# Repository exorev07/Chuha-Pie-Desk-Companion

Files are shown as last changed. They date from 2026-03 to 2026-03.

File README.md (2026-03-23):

<div align="center">
   
# Chuha Pie V1 - A cute Desk Companion
*An ESP32-powered animated desk companion with OLED eyes, touch interactions, Spotify controls, presence detection, and environmental monitoring, housed in a custom 3D-printed enclosure.*







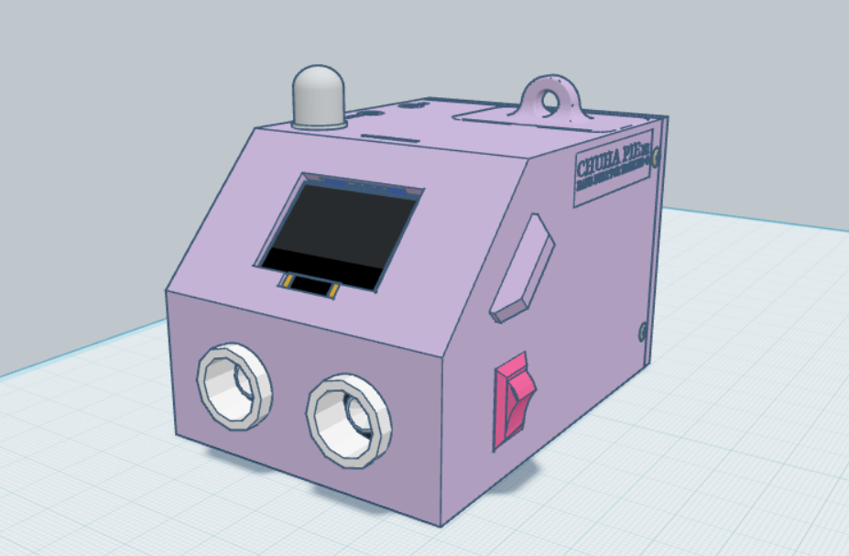
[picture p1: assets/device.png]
Device


</div>

---

## 📖 Table of Contents

- [Overview](#-overview)
- [Repository Structure](#-repository-structure)
- [Hardware](#-hardware)
- [Features](#-features)
- [Pin Connections](#-pin-connections)
- [Libraries Required](#-libraries-required)
- [Getting Started](#-getting-started)
- [Power](#-power)
- [License](#-license)

---

## 🔍 Overview

Chuha Pie V1 is a hand-built desk companion that I built for my girlfriend as her 20th birthday present, which sits on her desk and keeps her company. It uses an OLED display with animated eyes to express its mood, reacts to presence and touch, gives her break and water reminders, tracks and controls Spotify playback on any device using the account, runs a stopwatch and a Pomodoro timer, and measures distance digitally, along with ambient temperature and humidity in the room - all running on an ESP32.

**Key highlights:**

- **Animated OLED eyes** with blink, idle movement, and mood expressions.
- **Touch interactions** - tap, double tap, triple tap, and long press gestures.
- **Presence detection** via HC-SR04  greets and gets excited when it detects presence, gets sad otherwise.
- **Spotify control** - play/pause, next, previous track - through touch controls.
- **Pomodoro timer** with auto-start (10s), pause/resume, and configurable durations from the internal menu.
- **Passive wellness reminders** - posture alerts, break reminders, water reminders via RGB LED.
- **Environmental display** - temperature, humidity, distance readouts on demand
- **Deep sleep via physical switch** - turns off even with USB connected

---

## 📁 Repository Structure

```text
Chuha Pie V1/
├── 📂 3D Print Enclosure/
│   ├── back_plate.stl
│   ├── esp_button_connector.stl
│   └── main_body.stl
|
├── 📂 Main/
│   ├── Main.ino                      # Main firmware
│   └── example_secrets.h             # This is an example file - Upon downloading, rename to secrets.h and follow the instructions.
│
├── 📂 assets/
│   └── device.png                    # 3D render of the device
│
├── .gitignore
├── CMD Serial Monitor.txt            # Use to read serial data from ESP32 in Spotify Mode
├── spotify_get_refresh_token.py      # Helper script to generate Spotify refresh token
├── Chuha Pie User Manual.pdf         # Detailed instructions
├── LICENSE
└── README.md
```

---

## 🪛 Hardware

| Component | Model |
|---|---|
| Microcontroller | ESP32 DevKit V1 |
| Display | SSD1306 128×64 OLED (SPI, 7-pin) |
| Touch Sensor | TTP223 Capacitive Touch |
| Ultrasonic Range Sensor | HC-SR04 |
| Temp/Humidity | DHT11 |
| Indicator | RGB LED (Common Anode, 10mm diffused) |
| Haptics | 5V Vibration Motor Module (3-pin) |
| Sleep Control | SPST Switch (deep sleep via GPIO 35) |
| Power | USB via ESP32 DevKit V1 |

---

## ✨ Features

> See the [User Manual](./Chuha%20Pie%20User%20Manual.pdf) included in the repo for a full visual flowchart of touch interactions.

### Touch Interactions (TTP223)

| Gesture | Action |
|---|---|
| Single tap | Enter Feature Cycle (starts at Date & Time) |
| Double tap | Bonk animation |
| Triple tap | Open Settings |
| Long press (1s) | Cycle to next feature mode |
| Long press (2s+) | Pet the bot — happy animation |
| Long press (4s) | Return to Home Screen from any mode |

### Feature Cycle

**Home → Date & Time → Stopwatch → Pomodoro → Spotify → Distance → Temperature → Humidity → Home**

> **Shortcut**: Long press advances to the next mode. A 4-second long press from any mode jumps directly to home.

| Mode | Single Tap | Double Tap | Triple Tap |
|---|---|---|---|
| Date & Time | Toggle 12h / 24h format | — | — |
| Stopwatch | Start / Pause | Reset | — |
| Pomodoro (select) | Cycle duration options | — | — |
| Pomodoro (running) | Pause / Resume | — | — |
| Spotify | Play / Pause | Next song | Previous song |

### Settings (Triple Tap from Home)

- **Brightness**: 5 levels: 5% / 25% / 50% / 75% / 100%
- **Presence Range** (long press from Brightness): configures detection distance to 30 / 50 / 75 / 100 / 125 cm. The posture alert threshold adjusts proportionally (~40% of the detection distance).

### Automatic / Background Features

| Feature | Trigger | Indicator |
|---|---|---|
| Presence detection | Enters detection range | Greeting eye animation |
| Sad eyes | No presence for 30+ seconds | Eye animation |
| Break reminder | 1 hour of continuous presence | Green LED + vibration |
| Posture alert | Too close for 3+ seconds | Red LED + vibration (1 min cooldown) |
| Water reminder | Every hour / 1 min after 30+ min absence | Blue LED + vibration |
| Sweat animation | Temperature > 35°C | Eye animation (10s every 5 min) |
| Auto brightness | Time of day | 100% (7AM–7PM), 50% (7PM-7AM), 75% (No Internet default) |

---

## 📌 Pin Connections

### OLED Display (SPI)

| OLED Pin | ESP32 Pin |
|---|---|
| GND | GND |
| VDD | 3.3V |
| SCK | GPIO 18 (HSPI CLK) |
| SDA | GPIO 23 (HSPI MOSI) |
| RES | GPIO 4 |
| DC | GPIO 2 |
| CS | GPIO 5 |

### TTP223 Touch Sensor

| Pin | ESP32 Pin |
|---|---|
| VCC | 3.3V |
| GND | GND |
| SIG | GPIO 15 |

### HC-SR04 Ultrasonic Sensor

| Pin | ESP32 Pin |
|---|---|
| VCC | VIN (5V) |
| GND | GND |
| TRIG | GPIO 26 |
| ECHO | Voltage divider → GPIO 27 |

> ⚠️ **HC-SR04 ECHO outputs 5V but ESP32 GPIO is 3.3V tolerant only.**
> Wire a voltage divider on ECHO: `ECHO → 1kΩ → GPIO 27 → 2kΩ → GND` (divides 5V to ~3.3V)

### DHT11

| Pin | ESP32 Pin |
|---|---|
| VCC | 3.3V |
| GND | GND |
| DATA | GPIO 14 |

### RGB LED (Common Anode)

| Pin | ESP32 Pin | Notes |
|---|---|---|
| Anode (longest) | 3.3V | — |
| Red | GPIO 25 | 100Ω resistor in series |
| Green | GPIO 32 | No resistor (Vf ~3.0–3.4V) |
| Blue | GPIO 33 | No resistor (Vf ~3.0–3.4V) |

### Vibration Motor (3-pin module)

| Pin | ESP32 Pin |
|---|---|
| VCC | VIN (5V) |
| GND | GND |
| SIG | GPIO 13 |

### Power Switch

```
GND → 10kΩ → GPIO 35 → [switch] → 3.3V
```

- Switch **open (OFF)**: GPIO 35 reads LOW → ESP32 enters deep sleep
- Switch **closed (ON)**: GPIO 35 reads HIGH → device runs normally

> GPIO 35 is input-only with no internal pull resistor - the external 10kΩ to GND is required.

---

## 📚 Libraries Required

Install via Arduino IDE → **Tools → Manage Libraries**:

| Library | Author |
|---|---|
| `Adafruit SSD1306` | Adafruit |
| `Adafruit GFX Library` | Adafruit |
| `DHT sensor library` | Adafruit |
| `FluxGarage RoboEyes` | FluxGarage |

---

## 🚀 Getting Started

### Prerequisites

- [Arduino IDE](https://www.arduino.cc/en/software) (v1.8+ or v2.x)
- ESP32 board package installed in Arduino IDE
- Python 3.x (for Spotify token helper script)
- A 2.4GHz WiFi network
- Spotify Premium account _(for Spotify feature)_

### 1️⃣ Get the Code

```bash
git clone https://github.com/exorev07/Chuha-Pie-Desk-Companion.git
```

Or download the ZIP from GitHub and extract it.

### 2️⃣ Set Up Arduino IDE

1. Open Arduino IDE → **File → Preferences**
2. Under _Additional Boards Manager URLs_, paste:

   ```text
   https://raw.githubusercontent.com/espressif/arduino-esp32/gh-pages/package_esp32_index.json
   ```

3. Go to **Tools → Board → Boards Manager**, search `esp32`, and install it
4. Go to **Tools → Manage Libraries** and install all four libraries listed above

### 3️⃣ Configure Your Credentials

1. Copy `Main/example_secrets.h` and rename the copy to `Main/secrets.h`
2. Open `Main/secrets.h` and fill in your details:

   ```cpp
   #define WIFI_SSID_VAL     "WiFi Name (2.4GHz)"
   #define WIFI_PASSWORD_VAL "WiFi Password"

   #define SPOTIFY_CLIENT_ID_VAL     "paste Client ID here"
   #define SPOTIFY_CLIENT_SECRET_VAL "paste Client Secret here"
   #define SPOTIFY_REFRESH_TOKEN_VAL "paste Refresh Token here"
   ```

### 4️⃣ Setting Up Spotify

1. Go to [developer.spotify.com/dashboard](https://developer.spotify.com/dashboard) and create an app
2. Set the redirect URI to `http://127.0.0.1:8888/callback`
3. Copy your **Client ID** and **Client Secret** into `secrets.h`
4. Run the included helper script to get your Refresh Token:

   ```bash
   python spotify_get_refresh_token.py
   ```

5. Paste the printed Refresh Token into `secrets.h`

> Chuha Pie V1 can control whichever device is currently active on the Spotify account.

### 5️⃣ Upload to the Device

1. Plug in the device via USB
2. In Arduino IDE: **Tools → Board** → select **ESP32 Dev Module** or **DOIT ESP32 DevKit V1**
3. **Tools → Port** → select the COM port that appears (e.g. COM3 on Windows)
4. Click the **Upload** button (→)
5. If the IDE shows `Connecting...`, hold the **BOOT** button on the ESP32 until uploading starts
6. Wait for _"Done uploading"_ - Chuha Pie restarts automatically

---

## ⚡ Power

- Powered via USB through the ESP32 DevKit V1 
- The physical switch triggers ESP32 **deep sleep**
- To wake: flip the switch to ON (GPIO 35 goes HIGH, ESP32 exits deep sleep and reboots)

---

## 📜 License

This project is licensed under the **MIT License** - see the [LICENSE](LICENSE) file for details.

---

<div align="center">

**If you like this project, consider giving it a ⭐!**

_Built with 💜 for the love of my life._

</div>

---

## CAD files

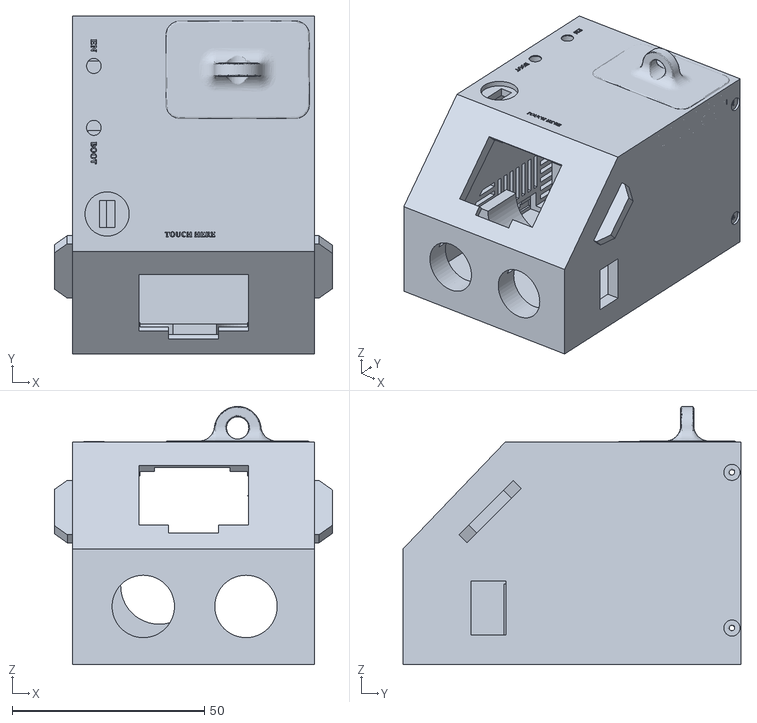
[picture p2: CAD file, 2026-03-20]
3D Print Enclosure/main_body.stl
72.5 x 88.0 x 67.2

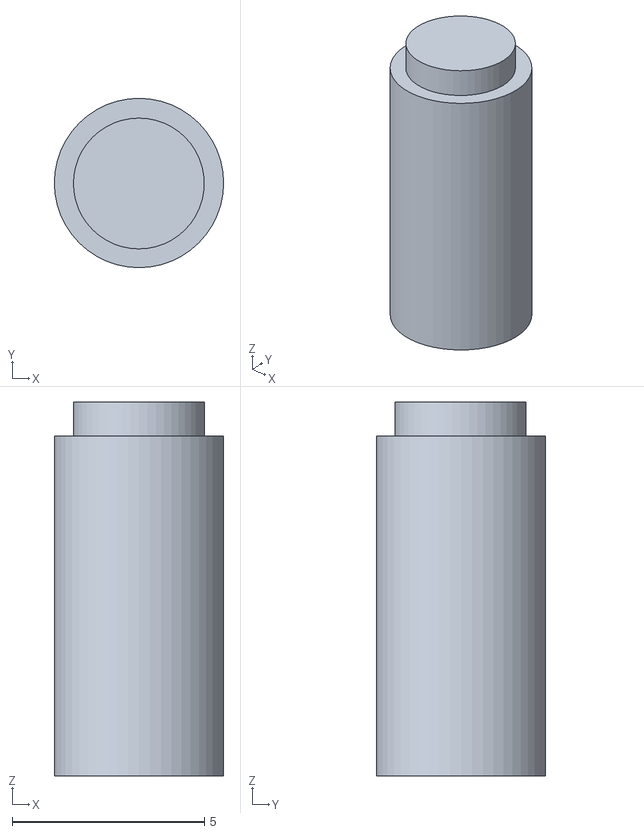
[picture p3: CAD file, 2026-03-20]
3D Print Enclosure/esp_button_connector.stl
4.40 x 4.40 x 9.72

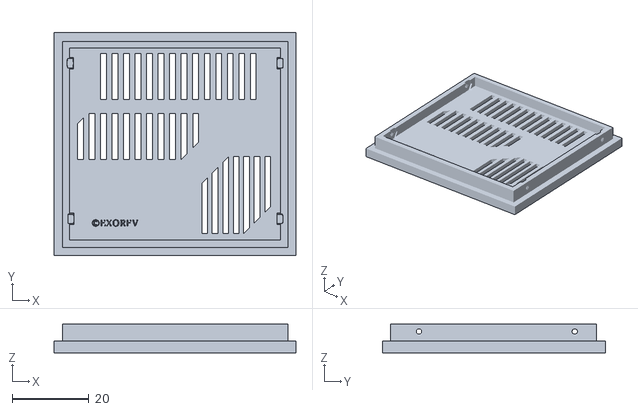
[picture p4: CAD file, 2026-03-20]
3D Print Enclosure/back_plate.stl
63.0 x 58.0 x 7.51

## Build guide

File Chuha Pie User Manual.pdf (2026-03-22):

# CHUHA PIE

V1

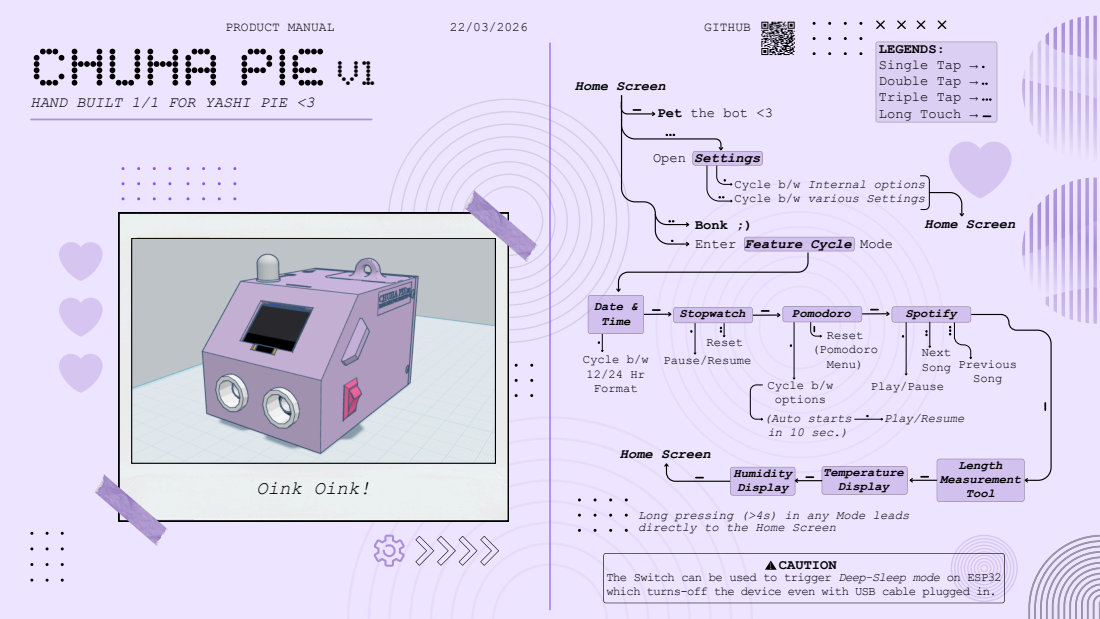
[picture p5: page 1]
Open Settings; Stopwatch; Pomodoro; Cycle b/w options (Auto starts in 10 sec.); Reset (Pomodoro Menu); Spotify; Next Song Previous Song; Length Measurement Tool; LEGENDS: Single Tap → Double Tap → Triple Tap → Long Touch →; CAUTION; Temperature Display; Home Screen; Humidity Display; Oink Oink!; PRODUCT MANUAL; Date & Time; Cycle b/w 12/24 Hr Format; Pause/Resume; Reset; Play/Pause; GITHUB; Play/Resume

HAND BUILT 1/1 FOR YASHI PIE <3

Pet the bot <3

Cycle b/w Internal options
Cycle b/w various Settings
Bonk ;)
Enter Feature Cycle Mode

Long pressing (>4s) in any Mode leads
directly to the Home Screen

The Switch can be used to trigger Deep-Sleep mode on ESP32
which turns-off the device even with USB cable plugged in.

# CHUHA PIE

### HAND BUILT 1/1 FOR YASHI PIE <3

V1

SETUP | 22/03/2026

GITHUB (https://github.com/exorev07/Chuha-Pie-Desk-Companion.git)

GETTING STARTED
What you'll need:
1.A computer with USB port.
2.Arduino IDE.
3.USB cable (Micro-USB) - Supplied with the device. 4.WiFi connection to use Spotify Controls and sync time. 5.Spotify Premium account (for Spotify feature).

STEP-1: GET THE CODE
1.Go to the GitHub link -
github.com/exorev07/Chuha-Pie-Desk-Companion.git 2.Download ZIP.
3.Extract the ZIP to access the code.
OR if you have Git installed: git clone.

STEP-2: SET UP ARDUINO IDE
1.Open Arduino IDE
2.Go to File → Preferences
3.Under Additional Boards Manager URLs, | paste:
4.Go to Tools → Board → Boards Manager, | search esp32, install it
5.Go to Tools → Manage Libraries, search and install:
Adafruit SSD1306
Adafruit GFX Library
DHT sensor library by Adafruit FluxGarage RoboEyes

https://raw.githubusercontent.com/espressif/arduino-%20esp32/gh-pages/package_esp32_index.json (https://raw.githubusercontent.com/espressif/arduino-%20esp32/gh-pages/package_esp32_index.json)

STEP-3: CONFIGURE YOUR CREDENTIALS
1.Open the extracted folder & open Main/secrets.h in Arduino IDE 2.Find these lines & fill them in:
#define WIFI_SSID_VAL "Enter 2.4Ghz SSID here" #define WIFI_PASSWORD_VAL "ENTER WIFI Password"

STEP-4: | SET UP SPOTIFY
1.Go to | developer.spotify.com/dashboard and log in
2.Click | Create App - name it anything, set redirect URI to
http://localhost:8888/callback
3.Copy your Client ID and Client Secret, Value into secrets.h: #define SPOTIFY_CLIENT_ID_VAL "Paste here"
#define SPOTIFY_CLIENT_SECRET_VAL "Paste here" 4.To get your Refresh Token:

Run spotify_get_refresh_token.py from the Product Repo. 5.Log in with your Spotify account and grant permissions 6.Copy the Refresh Token and paste it into secrets.h: #define SPOTIFY_REFRESH_TOKEN_VAL "Paste here"

STEP-5: UPLOAD TO THE DEVICE
1.Plug in Chuha Pie via USB
2.In Arduino IDE go to Tools → Board → select ESP32 Dev Module or DOIT ESP32 Devkit V1
3.Go to Tools → Port → select the COM port that appears (e.g. COM3 on Windows)
4.Click the Upload button.
5.Wait for IDE to upload and when it displays “connecting...” press and hold boot button on ESP32 and the Device will restart automatically.

Auto Brightness
The device adjusts screen brightness automatically
based on time of day
7:00 AM - 7:00 PM → Full brightness (100%)
7:00 PM – 7:00 AM → Dimmed (50%)
If the device can't connect to NTP server, it defaults to 75% brightness.

exorev07

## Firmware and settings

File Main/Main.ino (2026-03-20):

/*
 * Chuha Pie V1 - Desk Companion
 * 
 * Hardware:
 * - ESP32 DevKit V1
 * - 7-Pin SSD1306 OLED (128x64, SPI)
 * - TTP223 Capacitive Touch Sensor
 * - HC-SR04 Ultrasonic Distance Sensor
 * - DHT11 Temperature & Humidity Sensor
 * - Vibration Motor (5V, GPIO-driven)
 * - RGB LED (Common Anode, 10mm diffused)
 * 
 * Pin Connections:
 * OLED GND  -> ESP32 GND
 * OLED VDD  -> ESP32 3.3V
 * OLED SCK  -> ESP32 GPIO 18 (HSPI CLK)
 * OLED SDA  -> ESP32 GPIO 23 (HSPI MOSI)
 * OLED RES  -> ESP32 GPIO 4 (Reset)
 * OLED DC   -> ESP32 GPIO 2 (Data/Command)
 * OLED CS   -> ESP32 GPIO 5 (Chip Select)
 * 
 * TTP223 VCC -> ESP32 3.3V
 * TTP223 GND -> ESP32 GND
 * TTP223 SIG -> ESP32 GPIO 15
 * 
 * HC-SR04 VCC  -> ESP32 VIN or 5V pin
 * HC-SR04 GND  -> ESP32 GND
 * HC-SR04 TRIG -> ESP32 GPIO 26
 * HC-SR04 ECHO -> VOLTAGE DIVIDER -> ESP32 GPIO 27
 * 
 * ⚠️ IMPORTANT: HC-SR04 ECHO outputs 5V but ESP32 GPIO is 3.3V tolerant!
 * Use voltage divider on ECHO pin:
 *   ECHO -> 1kΩ resistor -> GPIO 27 -> 2kΩ resistor -> GND
 *   This divides 5V to ~3.3V (safe for ESP32)
 * 
 * DHT11 VCC  -> ESP32 3.3V
 * DHT11 GND  -> ESP32 GND
 * DHT11 DATA -> ESP32 GPIO 14
 * 
 * Vibration Motor VCC -> ESP32 VIN (5V)
 * Vibration Motor GND -> ESP32 GND
 * Vibration Motor SIG -> ESP32 GPIO 13
 * 
 * Power Switch:
 * GND -> 10kΩ -> GPIO 35 -> [switch] -> 3.3V
 * Switch open (OFF): GPIO35 LOW -> device enters deep sleep
 * Switch closed (ON): GPIO35 HIGH -> device runs
 *
 * RGB LED (Common Anode, 10mm diffused):
 * RGB LED Anode (longest pin) -> ESP32 3.3V
 * RGB LED Red   -> 100Ω resistor -> ESP32 GPIO 25
 * RGB LED Green -> ESP32 GPIO 32 (no resistor needed, Vf ~3.0-3.4V)
 * RGB LED Blue  -> ESP32 GPIO 33 (no resistor needed, Vf ~3.0-3.4V)
 * 
 * Features:
 * - Touch interactions: single tap (mode enter), double tap (bonk), triple tap (brightness)
 * - Long press (>2s): Happy mood with laugh animation + haptic feedback
 * - 1s long press: Cycles through modes (Time > Stopwatch > Pomodoro > Spotify > Distance > Temp > Humidity)
 * - 4s long press: Home shortcut (return to eyes from any display mode)
 * - Time display with 12hr/24hr toggle (tap to switch)
 * - Stopwatch with start/pause (tap) and reset (double tap)
 * - Pomodoro timer (30/45/60/90/120 min, pause/resume, 10s auto-start)
 * - Spotify control: play/pause (tap), next (double tap), prev (triple tap)
 * - Distance, temperature, humidity displays
 * - Brightness adjustment: 5 levels via 3 SSD1306 registers (triple tap from eyes)
 * - Time-based default brightness: 100% daytime (7AM-7PM), 50% nighttime
 * - Presence detection: greets on arrival, shows TIRED after 30s absence
 * - Break reminder: hourly while present (green LED)
 * - Posture alert: too close (<20cm for 3s) with 1min cooldown (red LED)
 * - Water reminder: hourly + 1min after return from 30min absence (blue LED)
 * - RGB LED pulses with vibration for 2s, then solid for 3s during alerts
 * - Sweat animation above 35°C (10s every 5min)
 * - Auto blink and idle eye movements
 */

#include <SPI.h>
#include <Adafruit_GFX.h>
#include <Adafruit_SSD1306.h>
#include <WiFi.h>
#include <WiFiClientSecure.h>
#include <HTTPClient.h>
#include "base64.h"
#include <time.h>
#include <DHT.h>
#include <FluxGarage_RoboEyes.h>
#include "secrets.h"

// ============ WIFI CREDENTIALS ============
const char* WIFI_SSID = WIFI_SSID_VAL;
const char* WIFI_PASSWORD = WIFI_PASSWORD_VAL;

// ============ SPOTIFY CREDENTIALS ============
// Edit credentials in secrets.h (that file is gitignored and never pushed)
const char* SPOTIFY_CLIENT_ID = SPOTIFY_CLIENT_ID_VAL;
const char* SPOTIFY_CLIENT_SECRET = SPOTIFY_CLIENT_SECRET_VAL;
const char* SPOTIFY_REFRESH_TOKEN = SPOTIFY_REFRESH_TOKEN_VAL;

// ============ TIME CONFIGURATION ============
const char* NTP_SERVER = "pool.ntp.org";
const long GMT_OFFSET_SEC = 19800;  // IST is GMT+5:30 (5.5 * 3600 = 19800 seconds)
const int DAYLIGHT_OFFSET_SEC = 0;   // India doesn't use daylight saving

// ============ PIN DEFINITIONS ============
#define OLED_MOSI   23
#define OLED_CLK    18
#define OLED_DC     2
#define OLED_CS     5
#define OLED_RESET  4
#define TOUCH_PIN   15
#define TRIG_PIN    26
#define ECHO_PIN    27 
#define DHT_PIN     14 
#define VIBRATION_PIN 13
#define LED_RED_PIN   25
#define LED_GREEN_PIN 32
#define LED_BLUE_PIN  33
#define POWER_SWITCH_PIN 35  // Input-only RTC GPIO, external 10kΩ pulldown to GND, switch to 3.3V

// RGB LED PWM channels (common anode: 0=full on, 255=off)
#define LED_RED_CH    0
#define LED_GREEN_CH  1
#define LED_BLUE_CH   2

// ============ DHT11 SENSOR CONFIG ============
#define DHT_TYPE DHT11
DHT dht(DHT_PIN, DHT_TYPE);

// ============ TEMPERATURE MONITORING ============
#define TEMP_CHECK_INTERVAL 10000   // Check temperature every 10 seconds
#define SWEAT_THRESHOLD 35.0        // Sweating animation above 35°C
#define SWEAT_INTERVAL 300000UL     // Sweat every 5 minutes
#define SWEAT_DURATION 10000        // Sweat for 10 seconds
unsigned long lastTempCheck = 0;
unsigned long lastSweatStart = 0;    // When last sweat episode started
float lastTemperature = 0;
bool isSweating = false;

// ============ DISTANCE SENSOR CONFIG ============
#define DISTANCE_CHECK_INTERVAL 500  // Check distance every 500ms
float smoothedDistance = 0;           // EMA-smoothed distance for display
bool smoothedDistanceInit = false;    // Whether EMA has been seeded
#define EMA_ALPHA 0.3                 // EMA weight (0.1=very smooth, 0.5=responsive)

// ============ DISTANCE SETTINGS ============
// Each index pairs a presence detection range with a posture alert threshold
const int detectionOptions[] = {30, 50, 75, 100, 125};  // cm — how far away to detect presence
const int postureOptions[]   = {15, 20, 30,  40,  50};  // cm — too-close posture threshold per level
int distanceSelected = 1;  // Default: 50cm detection / 20cm posture (matches original values)

// ============ DISPLAY SETUP ============
#define SCREEN_WIDTH  128
#define SCREEN_HEIGHT 64
#define MAX_FPS       30

Adafruit_SSD1306 display(SCREEN_WIDTH, SCREEN_HEIGHT, OLED_MOSI, OLED_CLK, 
                         OLED_DC, OLED_RESET, OLED_CS);
RoboEyes<Adafruit_SSD1306> eyes(display);

// ============ TOUCH STATE ============
bool lastTouchState = false;
unsigned long touchStartTime = 0;
unsigned long touchDuration = 0;
unsigned long lastTapTime = 0;
bool isLongPress = false;
bool homePressTriggered = false;           // Tracks 4s "home" long press (back to face)

// ============ PRESENCE DETECTION ============
bool personPresent = false;
bool wasPersonPresent = false;
unsigned long lastDistanceCheck = 0;
unsigned long greetingStartTime = 0;
unsigned long lastDistanceDisplayUpdate = 0;
bool rawPresenceDetected = false;           // Raw sensor reading
unsigned long presenceChangeTime = 0;       // When raw detection last changed
#define PRESENCE_GONE_DELAY 5000            // 5s before marking absent
#define PRESENCE_ARRIVE_DELAY 50           // 50ms before marking present
enum GreetingState {
  NO_GREETING,
  GREETING_CURIOUS,
  GREETING_HAPPY,
  GREETING_DONE
};
GreetingState greetingState = NO_GREETING;

// ============ BREAK REMINDER ============
unsigned long continuousPresenceStart = 0;   // When person was first detected
bool breakReminderShown = false;             // Prevent repeated reminders
#define BREAK_REMINDER_INTERVAL 3600000UL    // 1 hour in ms

// ============ POSTURE ALERT ============
#define POSTURE_SUSTAIN_TIME 3000         // Must stay too close for 3s before alert
#define POSTURE_COOLDOWN 60000UL          // Don't re-alert within 1 minute
bool tooCloseDetected = false;             // Raw: currently under threshold
unsigned long tooCloseStartTime = 0;       // When too-close was first detected
unsigned long lastPostureAlert = 0;        // When last posture alert was shown
bool postureAlertActive = false;           // Alert already fired for this episode

// ============ WATER REMINDER ============
#define WATER_REMINDER_INTERVAL 3600000UL  // Remind every 1 hour
#define WATER_RETURN_DELAY 60000UL         // 1 min after returning from long absence
#define LONG_ABSENCE_THRESHOLD 1800000UL   // 30 min counts as "long absence"
unsigned long lastWaterReminder = 0;        // When last water reminder was shown
unsigned long lastPresenceEnd = 0;          // When person last left (for absence tracking)
bool waterReturnReminderPending = false;    // Waiting to show return reminder
unsigned long waterReturnDetectTime = 0;    // When person returned after long absence

// ============ ANIMATION STATE ============
enum State {
  IDLE,
  LONG_PRESS_BUILDING,
  SHOWING_AFFECTION,
  WAITING_FOR_SECOND_TAP,
  WAITING_FOR_THIRD_TAP,
  SHOWING_TIME,
  STOPWATCH_MODE,
  POMODORO_SELECT,
  POMODORO_RUNNING,
  POMODORO_DONE,
  SPOTIFY_MODE,
  SHOWING_DISTANCE,
  SHOWING_TEMPERATURE,
  SHOWING_HUMIDITY,
  BRIGHTNESS_ADJUST,
  DISTANCE_ADJUST,
  BONKED,
  RECOVERING,
  BREAK_REMINDER,
  POSTURE_ALERT,
  WATER_REMINDER
};

State currentState = IDLE;
State previousState = IDLE;            // For returning after alerts (break/posture)
unsigned long stateStartTime = 0;

// ============ BRIGHTNESS CONFIG ============
const int brightnessOptions[] = {5, 25, 50, 75, 100};  // Percentage values
// Each level: {contrast, precharge, vcomh} - all three registers for wide range
const byte brightnessContrast[] =  {  5,  30, 100, 170, 255};
const byte brightnessPrecharge[] = {0x00, 0x11, 0x22, 0xF1, 0xF1}; // Phase1|Phase2
const byte brightnessVCOMH[] =     {0x00, 0x10, 0x20, 0x30, 0x40}; // VCOMH deselect level
int brightnessSelected = 2;  // Default: 50% (index 2)

// ============ POMODORO CONFIG ============
const int pomodoroOptions[] = {30, 45, 60, 90, 120};  // Minutes
const char* pomodoroLabels[] = {"30 Min", "45 Min", "1 Hr", "1.5 Hr", "2 Hr"};
int pomodoroSelected = 0;               // Currently highlighted option (0-4)
unsigned long pomodoroSelectionTime = 0; // When current option was selected
unsigned long pomodoroEndTime = 0;       // When the timer should end
bool pomodoroPaused = false;             // Whether the timer is paused
unsigned long pomodoroPausedRemaining = 0; // Remaining time when paused (ms)

// ============ STOPWATCH STATE ============
bool time24HourFormat = false;               // Toggle between 24hr and 12hr display
bool stopwatchRunning = false;
unsigned long stopwatchStartTime = 0;        // When stopwatch was started/resumed
unsigned long stopwatchElapsed = 0;           // Accumulated elapsed time in ms
unsigned long stopwatchLastDoubleTap = 0;     // For double-tap reset detection
bool stopwatchWaitingSecondTap = false;       // Waiting for potential second tap

// ============ SPOTIFY STATE ============
String spotifyAccessToken = "";
unsigned long spotifyTokenExpiry = 0;       // When current token expires
String spotifyTrackName = "";
String spotifyArtistName = "";
bool spotifyIsPlaying = false;
unsigned long spotifyProgressMs = 0;        // Current position in ms
unsigned long spotifyDurationMs = 0;        // Track duration in ms
unsigned long spotifyLastProgressUpdate = 0; // When progress was last fetched from API
unsigned long lastSpotifyPoll = 0;
#define SPOTIFY_POLL_INTERVAL 3000           // Poll every 3 seconds (progress interpolated between polls)
int spotifyTapCount = 0;                     // Track taps for single/double/triple
unsigned long spotifyLastTapTime = 0;        // When last tap happened in Spotify mode
#define SPOTIFY_TAP_WINDOW 700               // ms to wait for more taps
bool spotifyTapPending = false;              // Whether we're waiting for more taps

// ============ SETUP ============

// Helper to apply brightness registers from brightnessSelected index
void applyBrightness() {
  display.ssd1306_command(SSD1306_SETCONTRAST);
  display.ssd1306_command(brightnessContrast[brightnessSelected]);
  display.ssd1306_command(SSD1306_SETPRECHARGE);
  display.ssd1306_command(brightnessPrecharge[brightnessSelected]);
  display.ssd1306_command(SSD1306_SETVCOMDETECT);
  display.ssd1306_command(brightnessVCOMH[brightnessSelected]);
}

void setup() {
  Serial.begin(115200);

  // Initialize display
  if(!display.begin(SSD1306_SWITCHCAPVCC)) {
    for(;;);
  }
  display.clearDisplay();
  display.display();

  // Initialize outputs required for a clean goToSleep() shutdown
  pinMode(VIBRATION_PIN, OUTPUT);
  digitalWrite(VIBRATION_PIN, LOW);
  ledcSetup(LED_RED_CH, 5000, 8);
  ledcSetup(LED_GREEN_CH, 5000, 8);
  ledcSetup(LED_BLUE_CH, 5000, 8);
  ledcAttachPin(LED_RED_PIN, LED_RED_CH);
  ledcAttachPin(LED_GREEN_PIN, LED_GREEN_CH);
  ledcAttachPin(LED_BLUE_PIN, LED_BLUE_CH);
  ledOff();

  // Power switch: check BEFORE expensive boot (WiFi, animations)
  // If OFF at power-on, sleep immediately without running startup sequence
  pinMode(POWER_SWITCH_PIN, INPUT);
  if (digitalRead(POWER_SWITCH_PIN) == LOW) goToSleep();

  // --- Switch is ON, proceed with full boot ---

  // Initialize RoboEyes
  eyes.begin(SCREEN_WIDTH, SCREEN_HEIGHT, MAX_FPS);
  eyes.setAutoblinker(true, 3, 2);  // Auto blink every 3-5 seconds
  eyes.setIdleMode(true, 2, 3);     // Idle movements every 2-5 seconds

  // Configure eye appearance
  eyes.setWidth(45, 45);
  eyes.setHeight(30, 30);
  eyes.setBorderradius(10, 10);
  eyes.setSpacebetween(15);

  showStartupMessage(); // Show startup message
  connectToWiFi(); // Connect to WiFi
  wakeUpEyes(); // Wake up eyes
  dht.begin(); // Initialize DHT sensor
  pinMode(TOUCH_PIN, INPUT); // Setup touch sensor

  // Setup ultrasonic sensor
  pinMode(TRIG_PIN, OUTPUT);
  pinMode(ECHO_PIN, INPUT);
}

// ============ MAIN LOOP ============
void loop() {
  checkPresence();
  if (digitalRead(POWER_SWITCH_PIN) == LOW) goToSleep();
  handleTouch();
  updateState();
  
  // Only update eyes when not showing info displays
  if (currentState != SHOWING_TIME && currentState != STOPWATCH_MODE && currentState != SHOWING_DISTANCE && currentState != SHOWING_TEMPERATURE && currentState != SHOWING_HUMIDITY && currentState != POMODORO_SELECT && currentState != POMODORO_RUNNING && currentState != BREAK_REMINDER && currentState != SPOTIFY_MODE && currentState != POSTURE_ALERT && currentState != WATER_REMINDER && currentState != BRIGHTNESS_ADJUST && currentState != DISTANCE_ADJUST) {
    eyes.update();
  }
}

// ============ STARTUP MESSAGE ============
void showStartupMessage() {
  display.clearDisplay();
  display.setTextColor(SSD1306_WHITE);
  
  display.setTextSize(2);
  display.setCursor(2, 15);
  display.print("Chuha Pie");
  display.setTextSize(1);
  display.setCursor(114, 23);
  display.print("V1");
  
  display.setTextSize(1);
  display.setCursor(2, 40);
  display.println("Built for:");
  display.setCursor(30, 50);
  display.println("Yashi Pie <3");
  
  display.display();
  delay(3000);
  
  display.clearDisplay();
  display.display();
}

// ============ WAKE UP ANIMATION ============
void wakeUpEyes() {
  // Force eyes to center position before starting
  eyes.setPosition(DEFAULT);
  eyes.setMood(DEFAULT);
  eyes.setIdleMode(false, 2, 3);  // Disable idle during wake-up
  
  // Wake up sequence
  eyes.close();
  for(int i = 0; i < 30; i++) { eyes.update(); delay(33); }  // ~1s closed
  
  // Blink a few times (waking up)
  for(int i = 0; i < 3; i++) {
    eyes.open();
    for(int j = 0; j < 6; j++) { eyes.update(); delay(33); }  // ~200ms open
    eyes.close();
    for(int j = 0; j < 6; j++) { eyes.update(); delay(33); }  // ~200ms closed
  }
  
  // Open with happy mood
  eyes.open();
  eyes.setMood(HAPPY);
  for(int i = 0; i < 20; i++) { eyes.update(); delay(50); }  // ~1s happy
  
  // Settle to default
  eyes.setMood(DEFAULT);
  eyes.setPosition(DEFAULT);
  for(int i = 0; i < 30; i++) { eyes.update(); delay(33); }  // ~1s settle
  
  // Re-enable idle mode for main loop
  eyes.setIdleMode(true, 2, 3);
}

// ============ DISTANCE MEASUREMENT ============
// Single raw reading from HC-SR04
float getDistanceRaw() {
  digitalWrite(TRIG_PIN, LOW);
  delayMicroseconds(2);
  
  digitalWrite(TRIG_PIN, HIGH);
  delayMicroseconds(10);
  digitalWrite(TRIG_PIN, LOW);
  
  long duration = pulseIn(ECHO_PIN, HIGH, 30000); // 30ms timeout
  float distance = duration * 0.034 / 2;
  return distance;
}

// Smoothed reading: median of 5 rapid samples -> EMA filter
// Median rejects outlier spikes, EMA smooths valid jitter
float getDistance() {
  // Take 5 rapid readings
  float samples[5];
  for (int i = 0; i < 5; i++) {
    samples[i] = getDistanceRaw();
    if (i < 4) delayMicroseconds(500);  // Brief pause between pings
  }
  
  // Sort for median (simple insertion sort on 5 elements)
  for (int i = 1; i < 5; i++) {
    float key = samples[i];
    int j = i - 1;
    while (j >= 0 && samples[j] > key) {
      samples[j + 1] = samples[j];
      j--;
    }
    samples[j + 1] = key;
  }
  float median = samples[2];  // Middle value
  
  // Apply EMA (exponential moving average)
  if (!smoothedDistanceInit || median <= 0 || median >= 400) {
    // Seed EMA on first valid reading, or pass through invalid
    if (median > 0 && median < 400) {
      smoothedDistance = median;
      smoothedDistanceInit = true;
    }
    return median;
  }
  
  smoothedDistance = EMA_ALPHA * median + (1.0 - EMA_ALPHA) * smoothedDistance;
  return smoothedDistance;
}
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

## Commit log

2026-02-01 Initial code to test the Touch Sensor
2026-02-02 tried out implementing XERO's source code with the touch sensor
2026-02-13 added presence detection delay and ultrasonic sensor blip debounce
2026-02-18 fixed stopwatch and spotify modes
    [Main_RoboEyes_Version.ino]
2026-03-01 fixed mode cycle freezing issue when not connected to Wifi
    [Main.ino]
2026-03-01 added 3s override to go back to the eye display from any mode (shortcut)
    [Main.ino]
2026-03-01 fixed progress time fallback when song is paused in spotify mode
    [Main.ino]
2026-03-01 fixed song name - character overflow on the display
    [Main.ino]
2026-03-01 added sweat animations for ambient temps > 35℃
2026-03-02 added RGB LED logic for the alerts and improved their logic
2026-03-02 fixed few bugs in loading screen loop
    [Main.ino]
2026-03-02 fixed the delay in curious eyes state on presence detection
    [Main.ino]
2026-03-02 final code check and minor bug fix
    [Main.ino]
2026-03-20 added 3d enclosure files
    [back_plate.stl, esp_button_connector.stl, main_body.stl]
2026-03-20 fixed minor pomodoro bug
    [Main.ino]
2026-03-20 folder rename
    [back_plate.stl, esp_button_connector.stl, main_body.stl]
2026-03-22 added device user manual
2026-03-23 new 3D render of the device

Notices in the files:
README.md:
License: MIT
